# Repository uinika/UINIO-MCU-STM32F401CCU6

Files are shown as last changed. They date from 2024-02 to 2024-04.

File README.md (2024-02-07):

# UINIO-MCU-STM32F401CCU6 核心板

[**UINIO-MCU-STM32F401CCU6**](https://gitee.com/uinika/UINIO-MCU-STM32F401CCU6) 是一款基于 [**意法半导体**](https://www.st.com/zh/microcontrollers-microprocessors/stm32-32-bit-arm-cortex-mcus.html) **UFQFPN48** 封装的 **STM32F401CCU6** 微控制器的核心板电路设计，该微控制器基于 **ARM Cortex-M4** 内核架构，主频可以达到 `72MHz`，片上载有 `256KB` 容量的 Flash 存储器和 `64Kbytes` 的 SRAM 存储器，并且拥有 3 组 **USART** 和 3 组 **I²C** 接口，以及 4 组 **SPI** 接口与 `USB2.0` 全速控制器、12 位分辨率的 `ADC/DAC` 转换器，整体上属于高性价比、高性能的主控芯片产品。

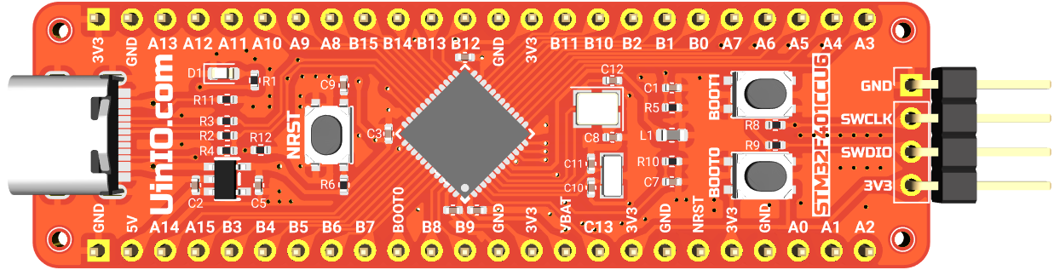
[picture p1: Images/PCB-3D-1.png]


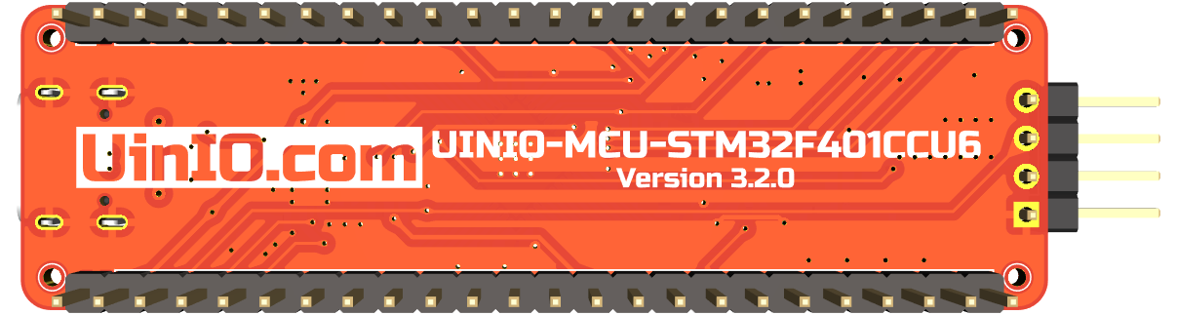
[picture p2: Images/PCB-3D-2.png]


> **注意**：相比较于采用 **ARM Cortex-M3** 内核架构的 **STM32F103C8T6** 等产品，使用 **ARM Cortex-M4** 内核的 **STM32F401CCU6** 携带有浮点计算单元（**FPU**，Float Point Unit），在处理数学计算时能够大幅度提升运算性能。

## 设计概要

1. 引出了意法半导体 **STM32F401CCU6** 型微控制器上面的全部 GPIO 引脚资源；
2. 单独提供有四线制的 **SWD** 下载接口，便于快速与 [UINIO-DAP-Link](http://uinio.com/Project/UINIO-DAP-Link) 建立连接；
3. 分别使用了 `8MHz` 与 `32.768KHz` 两枚贴片晶振作为系统外部时钟与实时时钟；
4. 板载 **BOOT0** 和 **BOOT1** 两枚启动配置按钮，以及一枚 **NRST** 复位按钮；
5. 模拟电源引脚 `VDDA` 使用了对 `100Mhz` 高频杂散信号存在 `1KΩ` 阻抗的**磁珠**进行单点接地；

## 启动配置

**UINIO-MCU-STM32F401CCU6** 通过板载的 `BOOT0` 和 `BOOT1` 两枚按钮来配置启动方式，默认情况下是从片上的 Flash 闪存进行启动，具体的配置信息可以参见下表：

| BOOT0 | BOOT1 | 启动方式 |
| :---: | :---: | :--- |
|  `0`  |  `X`  | 片上 Flash 闪存 |
|  `1`  |  `0`  | 系统存储器/ISP |
|  `1`  |  `1`  | 片上 SRAM 静态随机存储器 |

## 参考技术文档

[UinIO.com 电子技术实验室](http://uinio.com/) 为 UINIO-MCU-STM32F401CCU6 开源项目提供了如下一系列技术参考资料：

1. [《基于 HAL 与 LL 的 UINIO-MCU-STM32F401 开发实践》](http://uinio.com/Embedded/STM32F401/)
2. [《ARM 调试工具 UINIO-DAP-Link 应用详解》](http://uinio.com/Project/UINIO-DAP-Link/)
3. [《BOM 交互式物料清单与 PCB 布线在线预览》](http://uinio.com/archives/BOM/UINIO-MCU-STM32F401CCU6.html)

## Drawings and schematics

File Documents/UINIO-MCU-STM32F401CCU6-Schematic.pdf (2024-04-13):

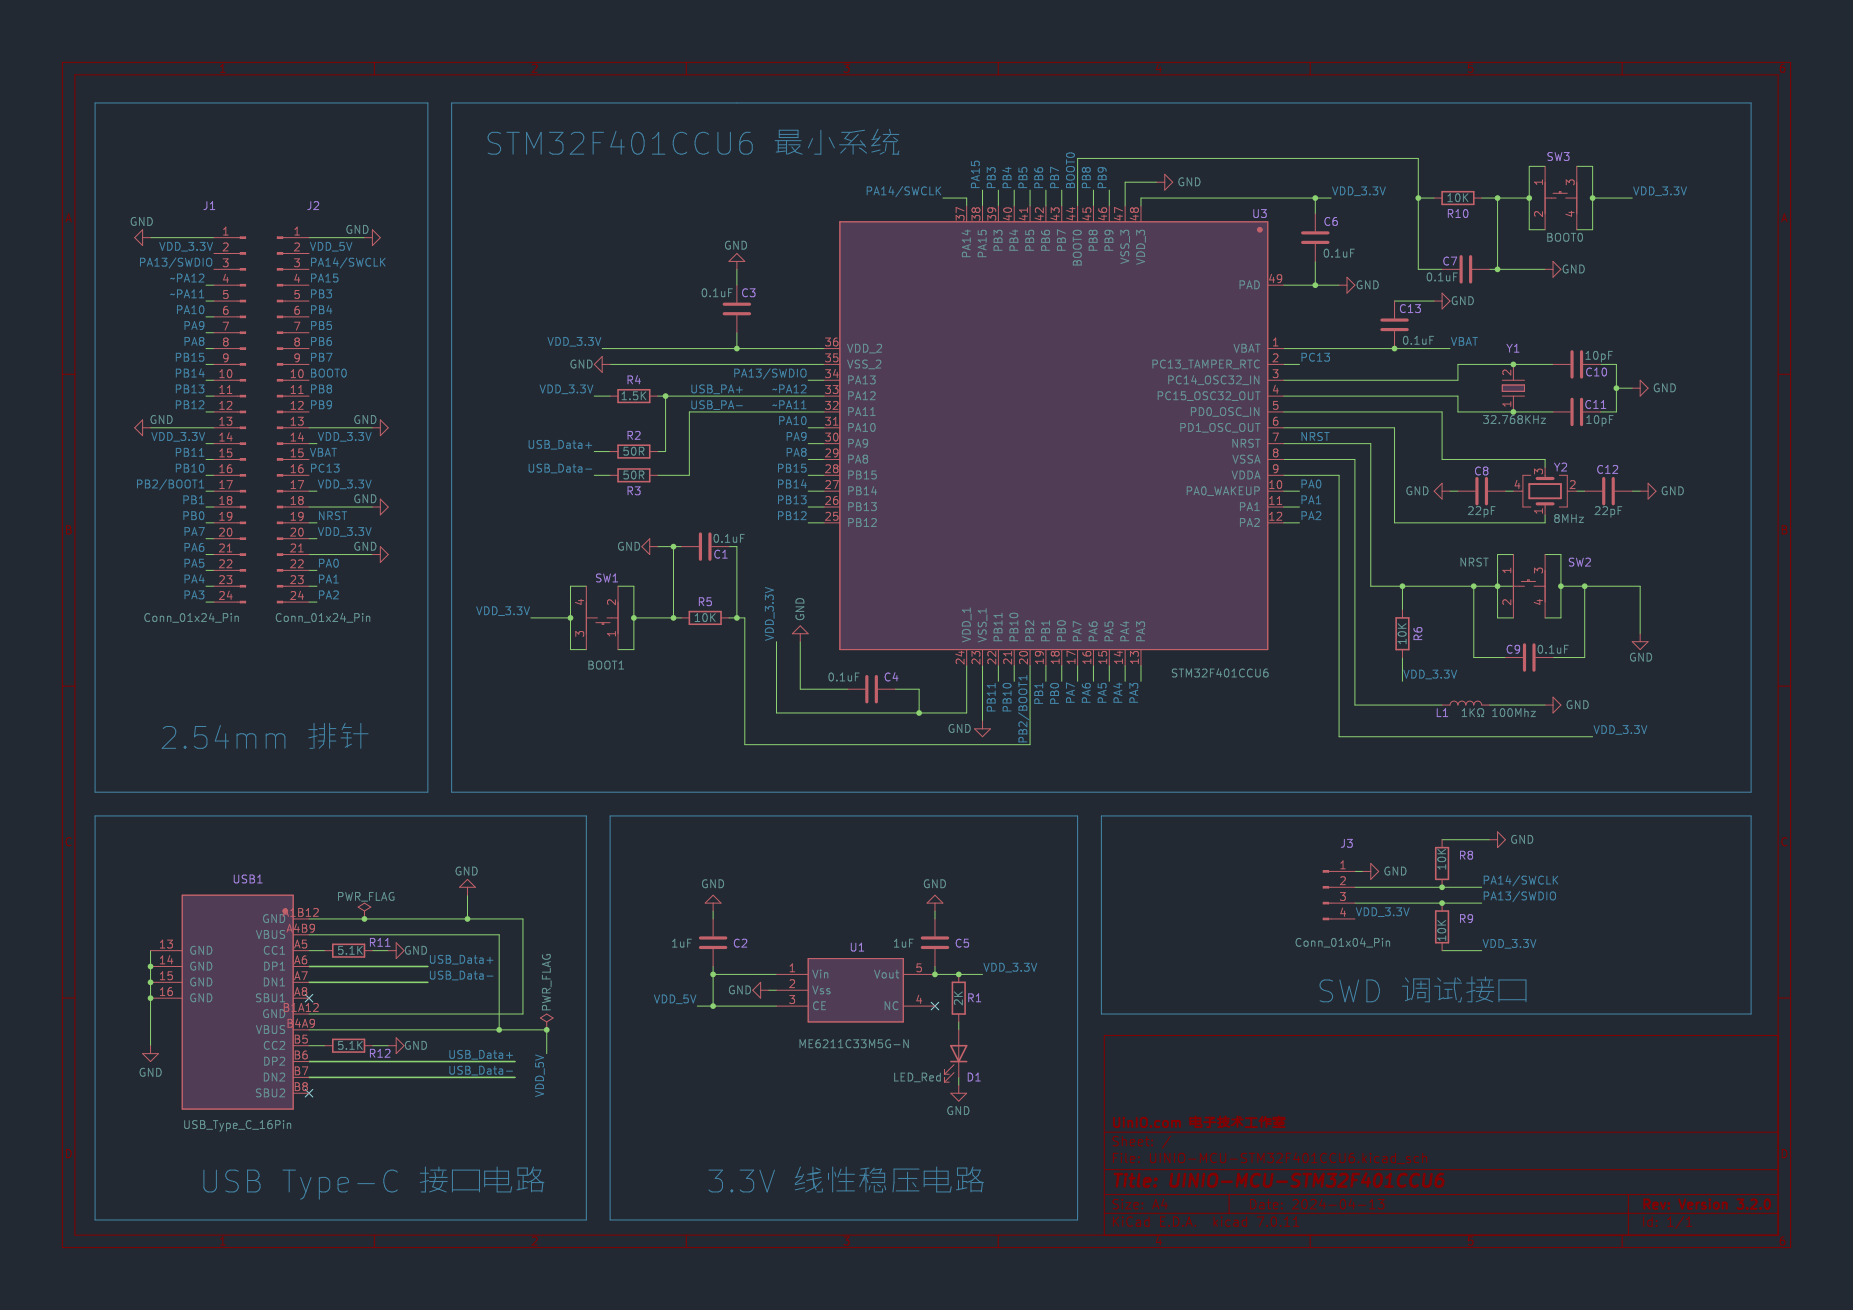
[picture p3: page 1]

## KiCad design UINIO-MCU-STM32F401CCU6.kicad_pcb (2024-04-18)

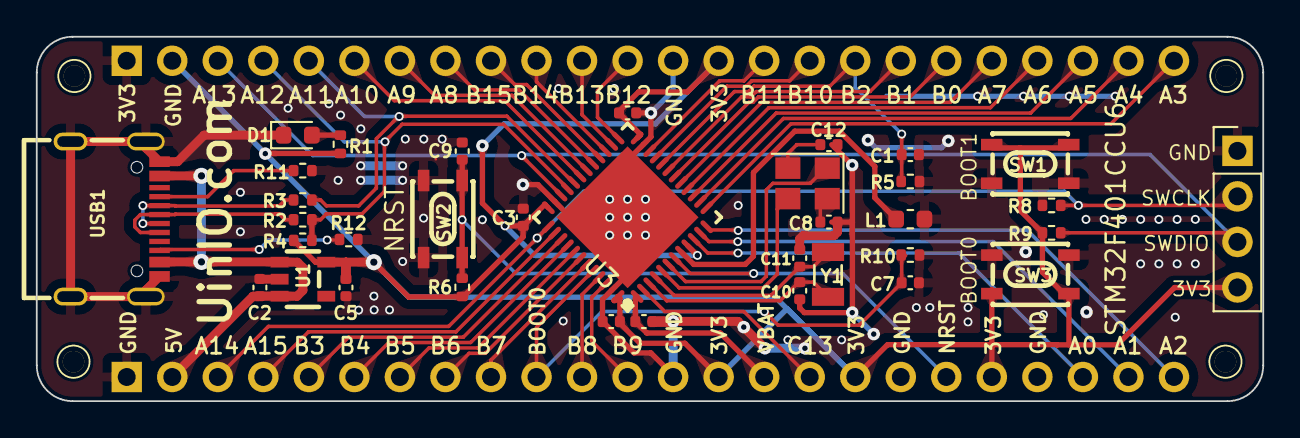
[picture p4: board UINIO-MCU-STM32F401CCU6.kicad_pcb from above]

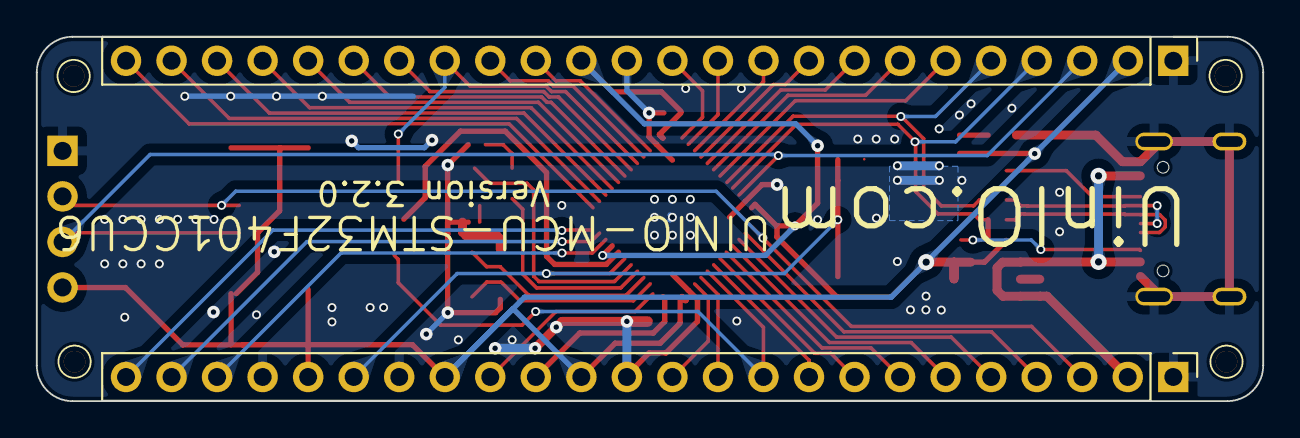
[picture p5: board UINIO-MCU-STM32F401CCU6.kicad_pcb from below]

Board: 2 copper layers, 68.4 x 20.3 mm, 41 parts (2 on the bottom side), 51 nets.

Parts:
C1, C3, C4, C6, C7, C9, C13: 0.1uF; C_0402_1005Metric
C2, C5: 1uF; C_0402_1005Metric
C8, C12: 22pF; C_0402_1005Metric
C10, C11: 10pF; C_0402_1005Metric
D1: LED_Red; LED_0603_1608Metric
HOLE**: Hole-1mm
HOLE**#2, HOLE**#3, HOLE**#4: Hole-1mm
J1, J2: Conn_01x24_Pin; PinHeader_1x24_P2.54mm_Vertical
J3: Conn_01x04_Pin; PinHeader_1x04_P2.54mm_Vertical
L1: 1KΩ 100Mhz; L_0603_1608Metric
R1: 2K; R_0402_1005Metric
R2, R3: 50R; R_0402_1005Metric
R4: 1.5K; R_0402_1005Metric
R5, R6, R8, R9, R10: 10K; R_0402_1005Metric
R11, R12: 5.1K; R_0402_1005Metric
SW1: BOOT1; KEY-SMD_4P-L4.2-W3.4-P2.15-LS4.7
SW2: NRST; KEY-SMD_4P-L4.2-W3.4-P2.15-LS4.7
SW3: BOOT0; KEY-SMD_4P-L4.2-W3.4-P2.15-LS4.7
U1: ME6211C33M5G-N; SOT-23-5_L3.0-W1.7-P0.95-LS2.8-BR
U3: STM32F401CCU6; UFQFPN-48_L7.0-W7.0-P0.50-TL-EP5.6
USB1: USB_Type_C_16Pin; USB-C-SMD_TYPEC-304J-BCP16
Y1: 32.768KHz; CRYSTAL-FC135-32.768
Y2: 8MHz; Crystal_SMD_3225-4Pin_3.2x2.5mm

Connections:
/BOOT0: C7.2, J2.10, R10.1, U3.44 (BOOT0)
/NRST: C9.1, J2.19, R6.2, SW2.1, SW2.2, U3.7 (NRST)
/PA0: J2.22, U3.10 (PA0_WAKEUP)
/PA1: J2.23, U3.11 (PA1)
/PA2: J2.24, U3.12 (PA2)
/PA3: J1.24, U3.13 (PA3)
/PA4: J1.23, U3.14 (PA4)
/PA5: J1.22, U3.15 (PA5)
/PA6: J1.21, U3.16 (PA6)
/PA7: J1.20, U3.17 (PA7)
/PA8: J1.8, U3.29 (PA8)
/PA9: J1.7, U3.30 (PA9)
/PA10: J1.6, U3.31 (PA10)
/PA13/SWDIO: J1.3, J3.3, R9.1, U3.34 (PA13)
/PA14/SWCLK: J2.3, J3.2, R8.2, U3.37 (PA14)
/PA15: J2.4, U3.38 (PA15)
/PB0: J1.19, U3.18 (PB0)
/PB1: J1.18, U3.19 (PB1)
/PB2/BOOT1: C1.2, J1.17, R5.1, U3.20 (PB2)
/PB3: J2.5, U3.39 (PB3)
/PB4: J2.6, U3.40 (PB4)
/PB5: J2.7, U3.41 (PB5)
/PB6: J2.8, U3.42 (PB6)
/PB7: J2.9, U3.43 (PB7)
/PB8: J2.11, U3.45 (PB8)
/PB9: J2.12, U3.46 (PB9)
/PB10: J1.16, U3.21 (PB10)
/PB11: J1.15, U3.22 (PB11)
/PB12: J1.12, U3.25 (PB12)
/PB13: J1.11, U3.26 (PB13)
/PB14: J1.10, U3.27 (PB14)
/PB15: J1.9, U3.28 (PB15)
/PC13: J2.16, U3.2 (PC13_TAMPER_RTC)
/USB_Data+: R2.1, USB1.A6 (DP1), USB1.B6 (DP2)
/USB_Data-: R3.1, USB1.A7 (DN1), USB1.B7 (DN2)
/USB_PA+: J1.4, R2.2, R4.2, U3.33 (PA12)
/USB_PA-: J1.5, R3.2, U3.32 (PA11)
/VBAT: C13.1, J2.15, U3.1 (VBAT)
/VDD_3.3V: C3.2, C4.2, C5.2, C6.2, J1.2, J1.14, J2.14, J2.17, J2.20, J3.4, R1.2, R4.1, R6.1, R9.2, SW1.3, SW1.4, SW3.3, SW3.4, U1.5 (Vout), U3.9 (VDDA), U3.24 (VDD_1), U3.36 (VDD_2), U3.48 (VDD_3)
/VDD_5V: C2.2, J2.2, U1.1 (Vin), U1.3 (CE), USB1.A4B9 (VBUS), USB1.B4A9 (VBUS)
GND: C1.1, C2.1, C3.1, C4.1, C5.1, C6.1, C7.1, C8.1, C9.2, C10.1, C11.1, C12.1, C13.2, D1.1 (K), J1.1, J1.13, J2.1, J2.13, J2.18, J2.21, J3.1, L1.1, R5.2, R8.1, R10.2, R11.2, R12.2, SW1.1, SW1.2, SW2.3, SW2.4, SW3.1, SW3.2, U1.2 (Vss), U3.23 (VSS_1), U3.35 (VSS_2), U3.47 (VSS_3), U3.49 (PAD), USB1.13 (GND), USB1.14 (GND), USB1.15 (GND), USB1.16 (GND), USB1.A1B12 (GND), USB1.B1A12 (GND)
unnamed: C8.2, Y2.4
unnamed: C12.2, Y2.2
unnamed: D1.2 (A), R1.1
unnamed: C10.2, U3.3 (PC14_OSC32_IN), Y1.2 (GND)
unnamed: C11.2, U3.4 (PC15_OSC32_OUT), Y1.1
unnamed: U3.5 (PD0_OSC_IN), Y2.3
unnamed: U3.6 (PD1_OSC_OUT), Y2.1
unnamed: L1.2, U3.8 (VSSA)
unnamed: R11.1, USB1.A5 (CC1)
unnamed: R12.1, USB1.B5 (CC2)

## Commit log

2024-02-06 Release UINIO-MCU-STM32F401CCU6 version 3.0.0.
    [UINIO-MCU-STM32F103C8T6-B_Cu.gbl, UINIO-MCU-STM32F103C8T6-B_Mask.gbs, UINIO-MCU-STM32F103C8T6-B_Paste.gbp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]
2024-04-12 Release UINIO-MCU-STM32F401CCU6 version 3.1.0.
    [UINIO-MCU-STM32F401CCU6.kicad_pcb, UINIO-MCU-STM32F401CCU6.kicad_sch]
2024-04-13 Release UINIO-MCU-STM32F401CCU6 version 3.2.0.
    [UINIO-MCU-STM32F401CCU6-B_Cu.gbl, UINIO-MCU-STM32F401CCU6-B_Mask.gbs, UINIO-MCU-STM32F401CCU6-B_Paste.gbp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]
